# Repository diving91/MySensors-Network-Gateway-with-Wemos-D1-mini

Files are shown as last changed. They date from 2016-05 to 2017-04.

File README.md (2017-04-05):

# MySensors-Network-Gateway-with-Wemos-D1-mini
WiFi Gateway for MySensors network

Arduino sketch and PCB for an ESP8266 based WiFi Gateway for MySensors network (NRF24)</br>
It uses a Wemos D1 mini and a NRF24L01+ module boards</br>
It uses a mains power supply

It fits perfectly in a small and low cost enclosure from  SUPERTRONIC reference PP73N :</br>
http://www.tme.eu/fr/details/pp73n/boitiers-dappar-dalarme-et-de-capt/supertronic/

Note that in this PCB the Wemos module is mounted with</br>
-ESP WiFi module bottom side</br>
-CH340 & USB upper side</br>
This is the opposite side of common usage, but it greatly ease the use of the USB connector</br>
This is easily done since the Wemos D1 mini module comes with unsoldered breakout pins</br>
Take care when soldering the wemos D1 mini's breakout pins to solder them accordingly to the PCB layout of this repository</br>

<b>Mounting view</b></br>
     CH340 USB driver</br>
-----Wemos PCB-----</br>
        WiFi module</br>
---------- PCB ----------</br>

See also in Pictures folder</br>
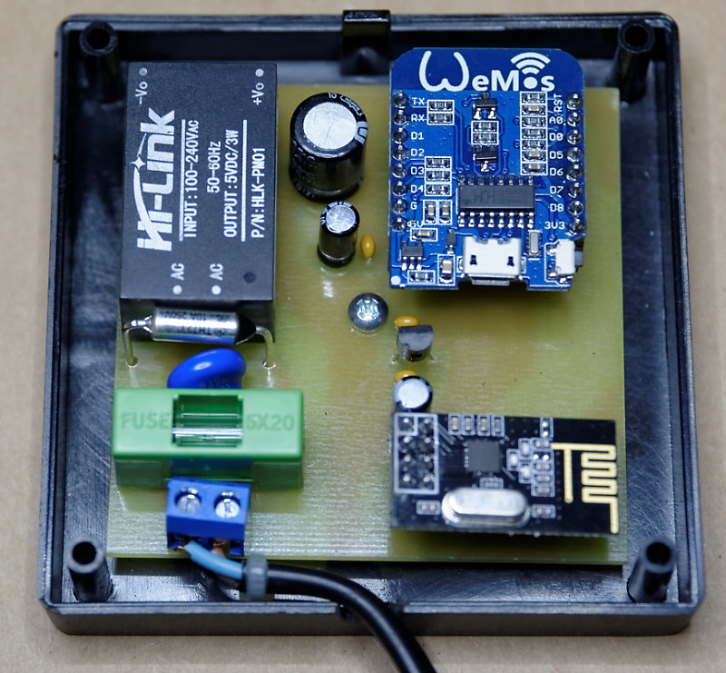
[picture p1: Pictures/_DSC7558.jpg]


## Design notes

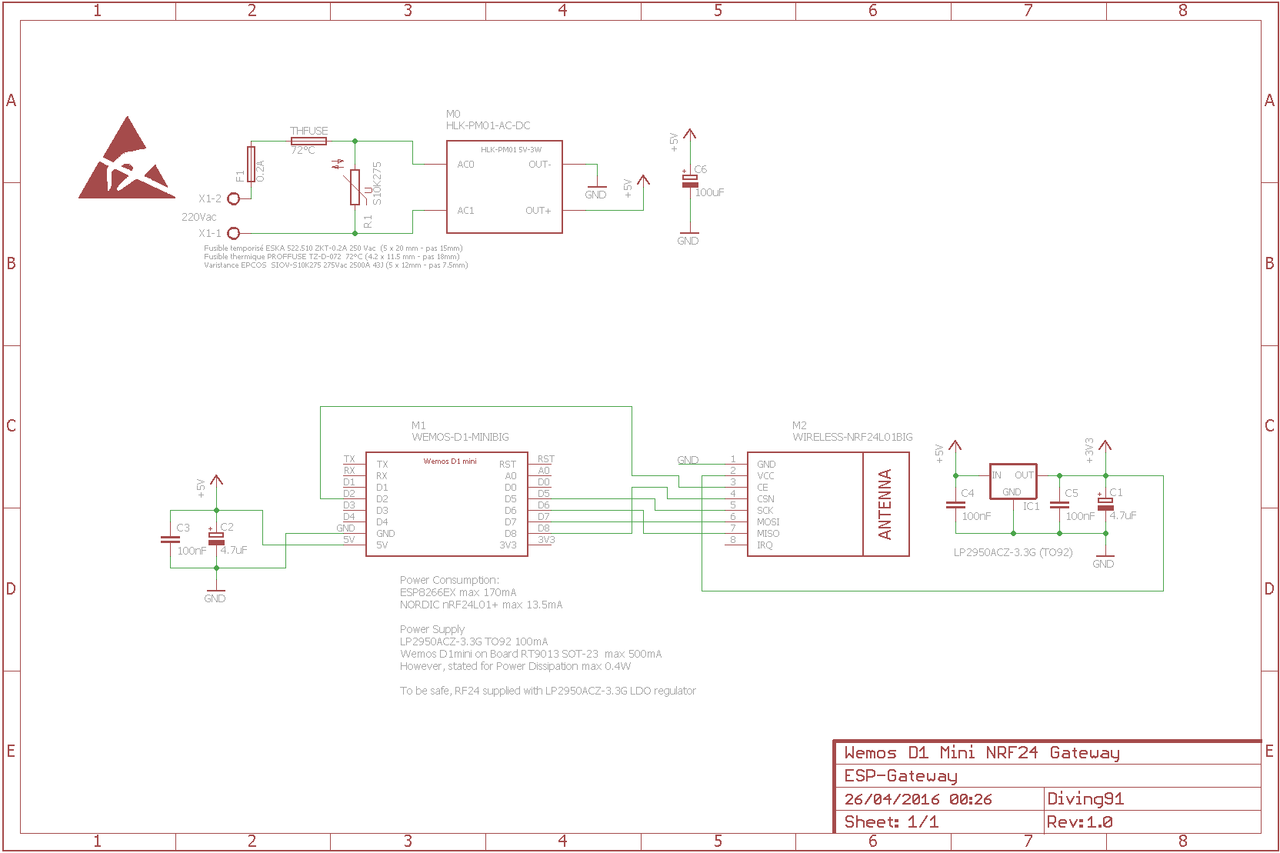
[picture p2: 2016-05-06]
Pictures/Node Schematics.png

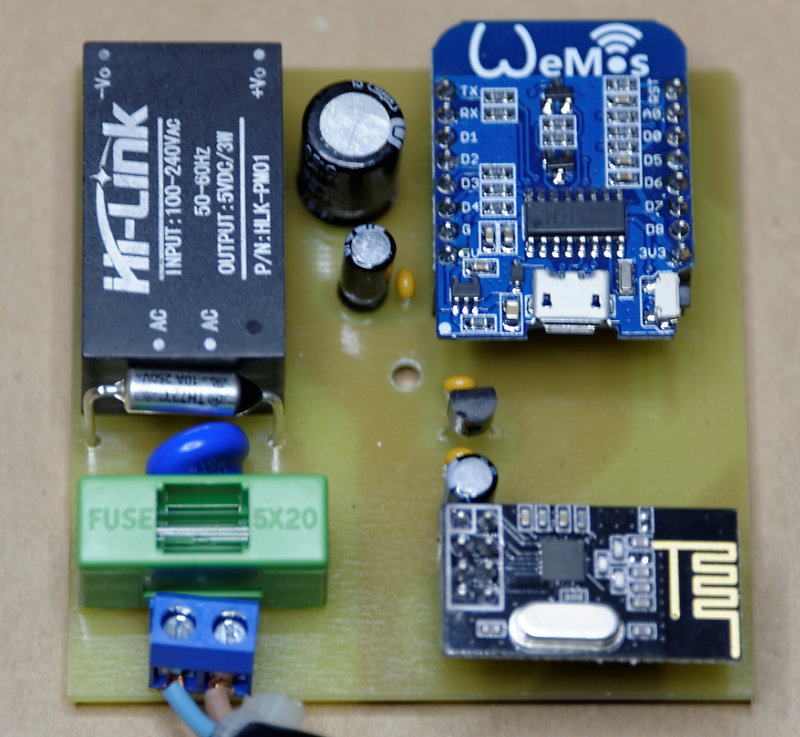
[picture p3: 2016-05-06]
Pictures/_DSC7557.jpg

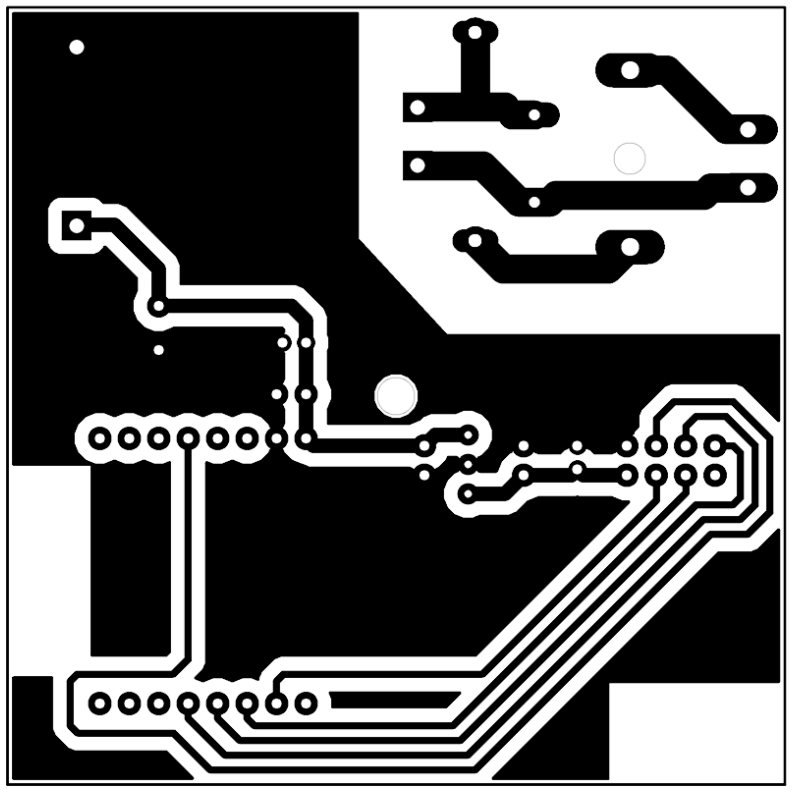
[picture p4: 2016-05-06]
Pictures/PCB view from copper side.png

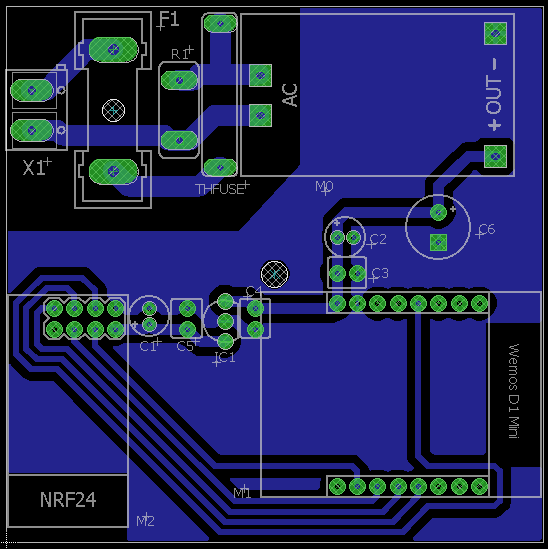
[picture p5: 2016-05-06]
Pictures/PCB Layout.png

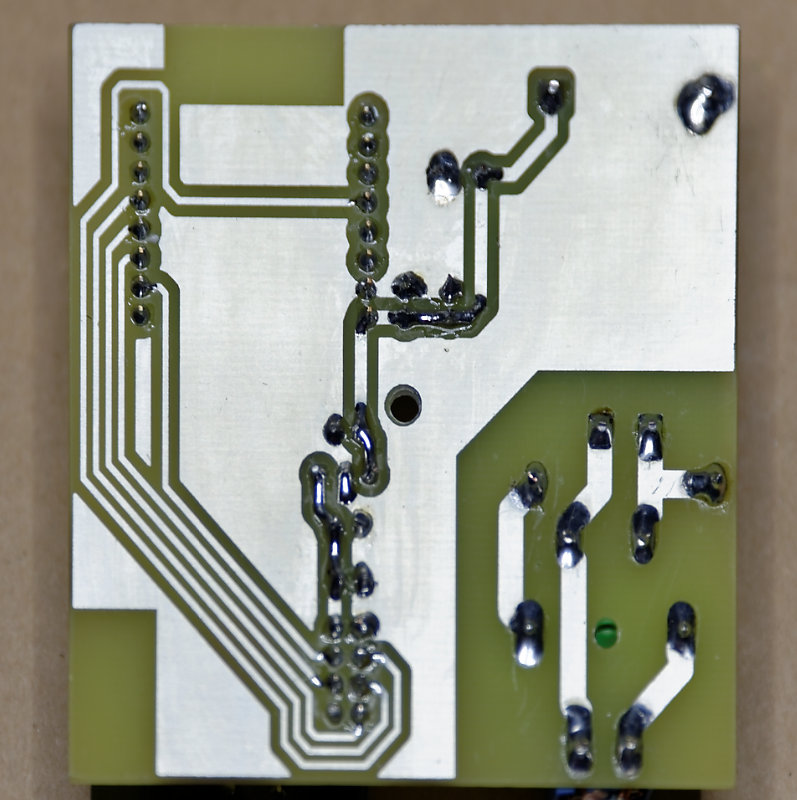
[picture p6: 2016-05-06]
Pictures/_DSC7555.jpg

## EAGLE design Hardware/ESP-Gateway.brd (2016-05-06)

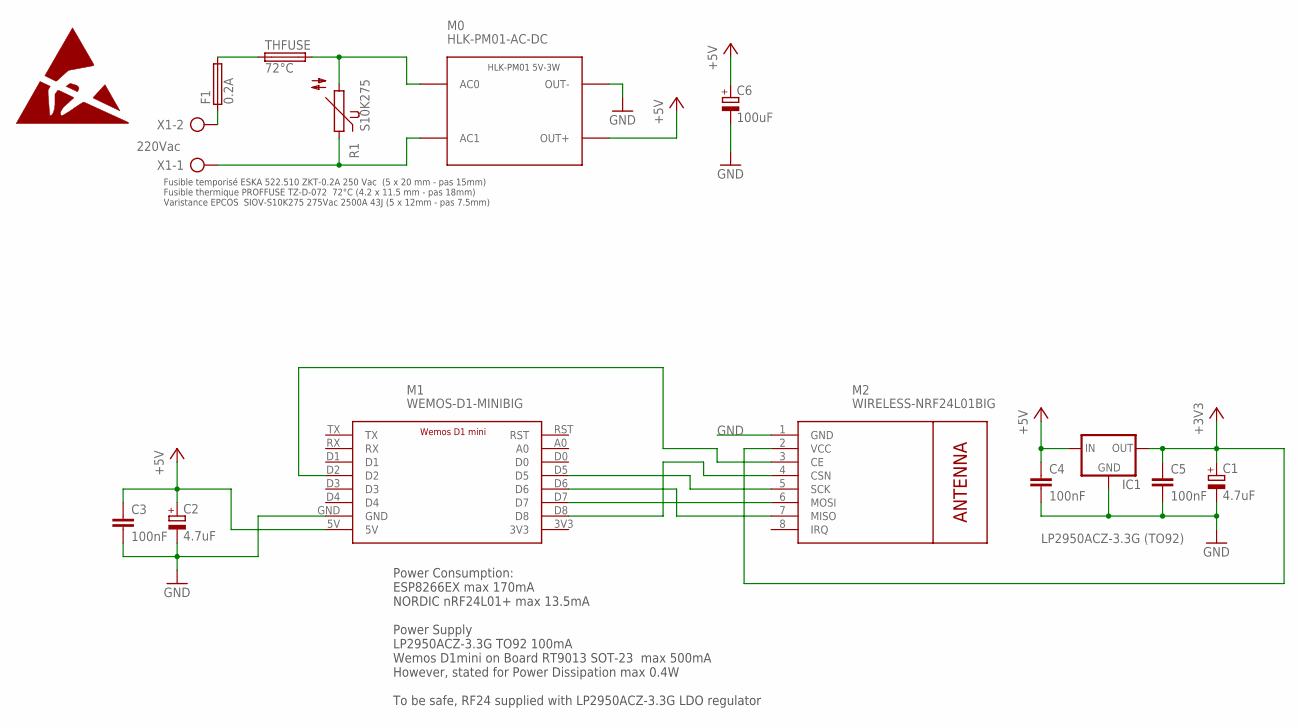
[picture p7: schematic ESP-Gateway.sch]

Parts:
C1, C2: 4.7uF; E2-5@1
C3, C4, C5: 100nF; C2.5-4
C6: 100uF; E3-8
F1: 0.2A; PTF75
IC1: LP2950ACZ-3.3G (TO92); DC-DC-TO92L
M0: HLK-PM01-AC-DC
M1: WEMOS-D1-MINIBIG; WEMOS-D1-MINI-DIY
M2: WIRELESS-NRF24L01BIG; WIRELESS-NRF24L01-DIY
R1: S10K275
THFUSE: 72°C; PROFFUSE-TZ-D
X1: 220Vac; DG301-5.0

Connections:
3V3: M1.3V3
+3V3: C1.+, C5.1, IC1.OUT, M2.2 (VCC)
+5V: C2.+, C3.1, C4.1, C6.+, IC1.IN, M0.OUT+, M1.5V
CE: M1.D2, M2.3 (CE)
CSN: M1.D8, M2.4 (CSN)
GND: C1.-, C2.-, C3.2, C4.2, C5.2, C6.-, IC1.GND, M0.OUT-, M1.GND, M2.1 (GND)
MISO: M1.D6, M2.7 (MISO)
MOSI: M1.D7, M2.6 (MOSI)
unnamed: M0.AC1, R1.1, X1.1
unnamed: F1.2, THFUSE.1
unnamed: F1.1, X1.2
unnamed: M0.AC0, R1.2, THFUSE.2
SCK: M1.D5, M2.5 (SCK)

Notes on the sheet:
Fusible temporisé ESKA 522.510 ZKT-0.2A 250 Vac (5 x 20 mm - pas 15mm) Fusible thermique PROFFUSE TZ-D-072 72°C (4.2 x 11.5 mm - pas 18mm) Varistance EPCOS SIOV-S10K275 275Vac 2500A 43J (5 x 12mm - pas 7.5mm)
Power Consumption: ESP8266EX max 170mA NORDIC nRF24L01+ max 13.5mA Power Supply LP2950ACZ-3.3G TO92 100mA Wemos D1mini on Board RT9013 SOT-23 max 500mA However, stated for Power Dissipation max 0.4W To be safe, RF24 supplied with LP2950ACZ-3.3G LDO regulator

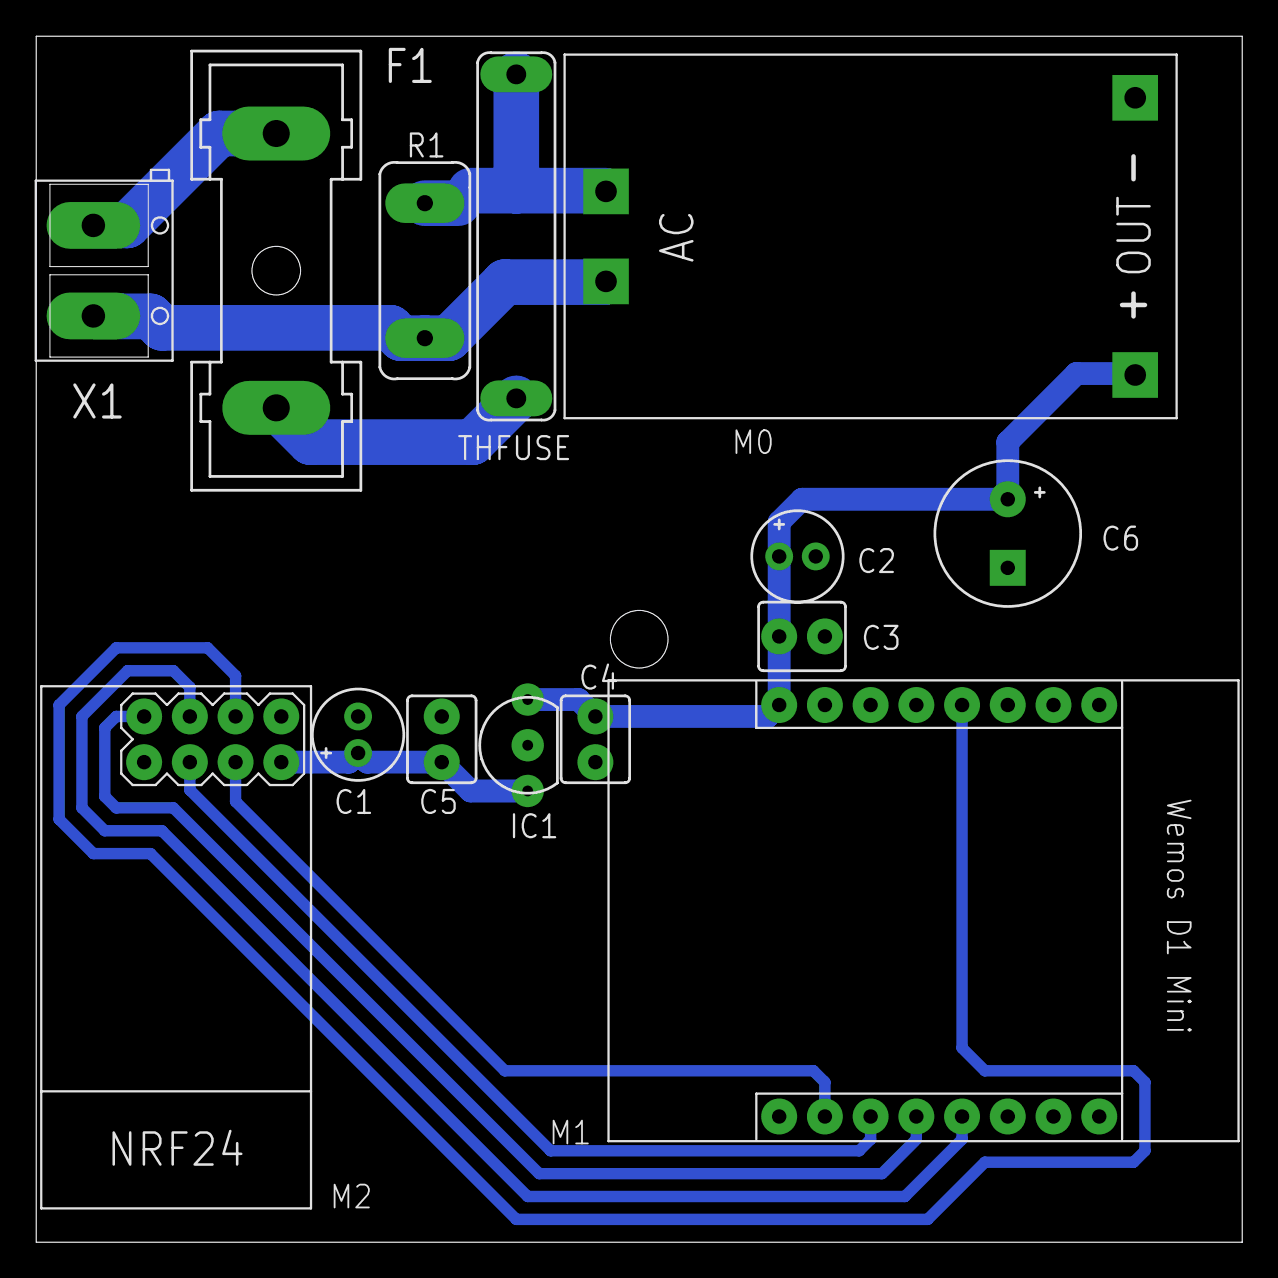
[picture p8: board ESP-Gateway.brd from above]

Board: 1 copper layer, 67.0 x 67.0 mm, 15 parts (0 on the bottom side), 12 nets.

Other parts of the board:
DRILEGEND: DRILEGEND

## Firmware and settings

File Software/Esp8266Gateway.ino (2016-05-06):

// Wemos D1 mini 160Mhz, Serial, 115200, 4M(3M SPIFFS), COMx
// Build with MySensors lib 1.5.4
// Build with ESP core lib 1.6.5-947-g39819f0

/**
 * The MySensors Arduino library handles the wireless radio link and protocol
 * between your home built sensors/actuators and HA controller of choice.
 * The sensors forms a self healing radio network with optional repeaters. Each
 * repeater and gateway builds a routing tables in EEPROM which keeps track of the
 * network topology allowing messages to be routed to nodes.
 *
 * Created by Henrik Ekblad <henrik.ekblad@mysensors.org>
 * Copyright (C) 2013-2015 Sensnology AB
 * Full contributor list: https://github.com/mysensors/Arduino/graphs/contributors
 *
 * Documentation: http://www.mysensors.org
 * Support Forum: http://forum.mysensors.org
 *
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
 *******************************
 *
 * REVISION HISTORY
 * Version 1.0 - Henrik EKblad
 * Contribution by a-lurker and Anticimex, 
 * Contribution by Norbert Truchsess <norbert.truchsess@t-online.de>
 * Contribution by Ivo Pullens (ESP8266 support)
 * 
 * DESCRIPTION
 * The EthernetGateway sends data received from sensors to the WiFi link. 
 * The gateway also accepts input on ethernet interface, which is then sent out to the radio network.
 *
 * VERA CONFIGURATION:
 * Enter "ip-number:port" in the ip-field of the Arduino GW device. This will temporarily override any serial configuration for the Vera plugin. 
 * E.g. If you want to use the defualt values in this sketch enter: 192.168.178.66:5003
 *
 * LED purposes:
 * - To use the feature, uncomment WITH_LEDS_BLINKING in MyConfig.h
 * - RX (green) - blink fast on radio message recieved. In inclusion mode will blink fast only on presentation recieved
 * - TX (yellow) - blink fast on radio message transmitted. In inclusion mode will blink slowly
 * - ERR (red) - fast blink on error during transmission error or recieve crc error  
 * 
 * See http://www.mysensors.org/build/ethernet_gateway for wiring instructions.
 * The ESP8266 however requires different wiring:
 * nRF24L01+  ESP8266
 * VCC        VCC
 * CE         GPIO4          
 * CSN/CS     GPIO15
 * SCK        GPIO14
 * MISO       GPIO12
 * MOSI       GPIO13
 *            
 * Not all ESP8266 modules have all pins available on their external interface.
 * This code has been tested on an ESP-12 module.
 * The ESP8266 requires a certain pin configuration to download code, and another one to run code:
 * - Connect REST (reset) via 10K pullup resistor to VCC, and via switch to GND ('reset switch')
 * - Connect GPIO15 via 10K pulldown resistor to GND
 * - Connect CH_PD via 10K resistor to VCC
 * - Connect GPIO2 via 10K resistor to VCC
 * - Connect GPIO0 via 10K resistor to VCC, and via switch to GND ('bootload switch')
 * 
  * Inclusion mode button:
 * - Connect GPIO5 via switch to GND ('inclusion switch')
 * 
 * Hardware SHA204 signing is currently not supported!
 *
 * Make sure to fill in your ssid and WiFi password below for ssid & pass.
 */
#define NO_PORTB_PINCHANGES 

#include <SPI.h>  

#include <MySigningNone.h> 
#include <MySigningAtsha204Soft.h>
#include <MyTransportNRF24.h>
#include <MyTransportRFM69.h>
#include <EEPROM.h>
#include <MyHwESP8266.h>
#include <ESP8266WiFi.h>

#include <MyParserSerial.h>  
#include <MySensor.h>  
#include <stdarg.h>
#include "GatewayUtil.h"

//Adapt to your network
const char *ssid =  "mySSID";    // cannot be longer than 32 characters!
const char *pass =  "myPWD"; //

#define INCLUSION_MODE_TIME 1 // Number of minutes inclusion mode is enabled
#define INCLUSION_MODE_PIN  5 // Digital pin used for inclusion mode button -> HSU D1 pin

#define RADIO_CE_PIN        4   // radio chip enable ->hsu number refer to gpio pin number ie D2 pin
#define RADIO_SPI_SS_PIN    15  // radio SPI serial select -> HSU D8 pin


#ifdef WITH_LEDS_BLINKING
#define RADIO_ERROR_LED_PIN BUILTIN_LED  // Error led pin
#define RADIO_RX_LED_PIN    BUILTIN_LED  // Receive led pin
#define RADIO_TX_LED_PIN    BUILTIN_LED  // the PCB, on board LED
#endif


// NRFRF24L01 radio driver (set low transmit power by default) 
MyTransportNRF24 transport(RADIO_CE_PIN, RADIO_SPI_SS_PIN, RF24_PA_LEVEL_GW);
//MyTransportRFM69 transport;


// Message signing driver (signer needed if MY_SIGNING_FEATURE is turned on in MyConfig.h)
#ifdef MY_SIGNING_FEATURE
MySigningNone signer;
//MySigningAtsha204Soft signer;
#endif

// Hardware profile 
MyHwESP8266 hw;

// Construct MySensors library (signer needed if MY_SIGNING_FEATURE is turned on in MyConfig.h)
// To use LEDs blinking, uncomment WITH_LEDS_BLINKING in MyConfig.h
MySensor gw(transport, hw
#ifdef MY_SIGNING_FEATURE
    , signer
#endif
#ifdef WITH_LEDS_BLINKING
  , RADIO_RX_LED_PIN, RADIO_TX_LED_PIN, RADIO_ERROR_LED_PIN
#endif
  );
  

#define IP_PORT 5003         // The port you want to open 
#define MAX_SRV_CLIENTS 3    // how many clients should be able to telnet to this ESP8266 - ie 2 JEEDOM + 1 Telnet

// a R/W server on the port
static WiFiServer server(IP_PORT);
static WiFiClient clients[MAX_SRV_CLIENTS];
static bool clientsConnected[MAX_SRV_CLIENTS];
static inputBuffer inputString[MAX_SRV_CLIENTS];

#define ARRAY_SIZE(x)  (sizeof(x)/sizeof(x[0]))

void output(const char *fmt, ... ) {
	char serialBuffer[MAX_SEND_LENGTH];
	va_list args;
	va_start (args, fmt );
	vsnprintf_P(serialBuffer, MAX_SEND_LENGTH, fmt, args);
	va_end (args);
	Serial.print(serialBuffer);
	for (uint8_t i = 0; i < ARRAY_SIZE(clients); i++) {
		if (clients[i] && clients[i].connected()) {
//			Serial.print("Client "); Serial.print(i); Serial.println(" write");
			clients[i].write((uint8_t*)serialBuffer, strlen(serialBuffer));
		}
	}
}

// HSU To display MAC Address
uint8_t MAC_array[6];
char MAC_char[18];

void setup() { 
	// Setup console
	hw_init();
	Serial.begin(115200);
	Serial.println(); Serial.println();
	Serial.println("ESP8266 MySensors Gateway");
	Serial.print("Connecting to "); Serial.println(ssid);

	(void)WiFi.begin(ssid, pass);
	// HSU Addition to disable AP and display MAC address
	WiFi.mode(WIFI_STA);
	WiFi.macAddress(MAC_array);
	Serial.print("MAC Address = ");
	for (int i = 0; i < sizeof(MAC_array); ++i){
		sprintf(MAC_char,"%s%02x:",MAC_char,MAC_array[i]);
	}
	Serial.println(MAC_char); //- See more at: http://www.esp8266.com/viewtopic.php?f=29&t=3587
	// End HSU
	
	while (WiFi.status() != WL_CONNECTED) {
		delay(500);
		Serial.print(".");
	}
	Serial.println("Connected!");
	Serial.print("IP: "); Serial.println(WiFi.localIP());
	Serial.println(); Serial.println(); //HSU
	Serial.flush();
  
	setupGateway(INCLUSION_MODE_PIN, INCLUSION_MODE_TIME, output);

	// Initialize gateway at maximum PA level, channel 70 and callback for write operations 
	gw.begin(incomingMessage, 0, true, 0);
  
	// start listening for clients
	server.begin();
	server.write("0;0;3;0;2;");server.write(LIBRARY_VERSION);  //HSU needed for Jeedom plugin
	server.setNoDelay(true);  
}

void loop() {
	gw.process();  
  
	checkButtonTriggeredInclusion();
	checkInclusionFinished();

	// Go over list of clients and stop any that are no longer connected.
	// If the server has a new client connection it will be assigned to a free slot.
	bool allSlotsOccupied = true;
	for (uint8_t i = 0; i < ARRAY_SIZE(clients); i++){
		if (!clients[i].connected()) {
			if (clientsConnected[i]) {
				Serial.print("Client "); Serial.print(i); Serial.println(" disconnected");
				clients[i].stop();
			}
			//check if there are any new clients
			if (server.hasClient()) {
				clients[i] = server.available();
				inputString[i].idx = 0;
				Serial.print("Client "); Serial.print(i); Serial.println(" connected"); 
				output(PSTR("0;0;%d;0;%d;Gateway startup complete.\n"),  C_INTERNAL, I_GATEWAY_READY);
			}
		}
		bool connected = clients[i].connected();
		clientsConnected[i] = connected;
		allSlotsOccupied &= connected;
	}
	if (allSlotsOccupied && server.hasClient()){
		//no free/disconnected spot so reject
		Serial.println("No free slot available");
		WiFiClient c = server.available();
		c.stop();
	}
  
	// Loop over clients connect and read available data
	for (uint8_t i = 0; i < ARRAY_SIZE(clients); i++){
		while(clients[i].connected() && clients[i].available()){
			char inChar = clients[i].read();
			if ( inputString[i].idx < MAX_RECEIVE_LENGTH - 1 ){ 
				// if newline then command is complete
				if (inChar == '\n'){  
					// a command was issued by the client
					// we will now try to send it to the actuator
					inputString[i].string[inputString[i].idx] = 0;
    
					// echo the string to the serial port
					Serial.print("Client "); Serial.print(i); Serial.print(": "); Serial.println(inputString[i].string);
    
					parseAndSend(gw, inputString[i].string);
    
					// clear the string:
					inputString[i].idx = 0;
					// Finished with this client's message. Next loop() we'll see if there's more to read.
					break;
				}
				else {  
					// add it to the inputString:
					inputString[i].string[inputString[i].idx++] = inChar;
				}
			}
			else {
				// Incoming message too long. Throw away 
				Serial.print("Client "); Serial.print(i); Serial.println(": Message too long");
				inputString[i].idx = 0;
				// Finished with this client's message. Next loop() we'll see if there's more to read.
				break;
			}
		}
	}
}

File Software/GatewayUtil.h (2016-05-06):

#ifndef __GATEWAYUTIL_H__
#define __GATEWAYUTIL_H__

#ifdef ARDUINO

static uint8_t inclusionTime = 1; // Number of minutes inclusion mode is enabled
static uint8_t pinInclusion =  5; // Input pin that should trigger inclusion mode

#define MAX_RECEIVE_LENGTH 100 // Max buffersize needed for messages coming from controller
#define MAX_SEND_LENGTH 120 // Max buffersize needed for messages destined for controller


typedef struct {
	char    string[MAX_RECEIVE_LENGTH];
	uint8_t idx;
} inputBuffer;

static volatile boolean buttonTriggeredInclusion;
static boolean inclusionMode; // Keeps track on inclusion mode
bool inclusionButtonSupported = false;
void (*serial)(const char *fmt, ... );

MyParserSerial parser;

void setInclusionMode(boolean newMode);

char convBuf[MAX_PAYLOAD*2+1];
unsigned long inclusionStartTime;


void startInclusionInterrupt() {
	buttonTriggeredInclusion = true;
}

void setupGateway(uint8_t _inc, uint8_t _incTime, void (* _serial)(const char *, ... )) {
	inclusionMode = 0;
	buttonTriggeredInclusion = false;
	serial = _serial;

	inclusionTime = _incTime;
	inclusionButtonSupported = (_inc != 255);
	if (inclusionButtonSupported){
		pinInclusion = _inc;

		// Setup digital in that triggers inclusion mode
		pinMode(pinInclusion, INPUT_PULLUP);

		// Add interrupt for inclusion button to pin
		attachInterrupt(pinInclusion, startInclusionInterrupt, FALLING);
	}
}

void incomingMessage(const MyMessage &message) {
	//  if (mGetCommand(message) == C_PRESENTATION && inclusionMode) {
	//	gw.rxBlink(3);
	//   } else {
	//	gw.rxBlink(1);
	//   }
	// Pass along the message from sensors to serial line
	serial(PSTR("%d;%d;%d;%d;%d;%s\n"),message.sender, message.sensor, mGetCommand(message), mGetAck(message), message.type, message.getString(convBuf));
} 



void checkButtonTriggeredInclusion() {
	if (inclusionButtonSupported){
		if (buttonTriggeredInclusion) {
			// Ok, someone pressed the inclusion button on the gateway
			// start inclusion mode for 1 munute.
			#ifdef DEBUG
				serial(PSTR("0;0;%d;0;%d;Inclusion started by button.\n"),  C_INTERNAL, I_LOG_MESSAGE);
			#endif
			buttonTriggeredInclusion = false;
			setInclusionMode(true);
		}
	}
}

void checkInclusionFinished() {
	if (inclusionMode && millis()-inclusionStartTime>60000UL*inclusionTime) {
		// inclusionTimeInMinutes minute(s) has passed.. stop inclusion mode
		setInclusionMode(false);
	}
}

void parseAndSend(MySensor &gw, char *commandBuffer) {
	boolean ok;
	MyMessage &msg = gw.getLastMessage();

	if (parser.parse(msg, commandBuffer)) {
		uint8_t command = mGetCommand(msg);

		if (msg.destination==GATEWAY_ADDRESS && command==C_INTERNAL) {
			// Handle messages directed to gateway
			if (msg.type == I_VERSION) {
				// Request for version
				serial(PSTR("0;0;%d;0;%d;%s\n"), C_INTERNAL, I_VERSION, LIBRARY_VERSION);
			}
			else if (msg.type == I_INCLUSION_MODE) {
				// Request to change inclusion mode
				setInclusionMode(atoi(msg.data) == 1);
			}
		}
		else {
			#ifdef WITH_LEDS_BLINKING
				gw.txBlink(1);
			#endif
			ok = gw.sendRoute(msg);
			if (!ok) {
				#ifdef WITH_LEDS_BLINKING
					gw.errBlink(1);
				#endif
			}
		}
	}
}

void setInclusionMode(boolean newMode) {
	if (newMode != inclusionMode) {
		inclusionMode = newMode;
		// Send back mode change on serial line to ack command
		serial(PSTR("0;0;%d;0;%d;%d\n"), C_INTERNAL, I_INCLUSION_MODE, inclusionMode?1:0);

		if (inclusionMode) {
			inclusionStartTime = millis();
		}
	}
}


#else
#error This example is only for use on Arduino.
#endif // ARDUINO

#endif 

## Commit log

2016-05-06 Node Schematics
2016-05-06 PCB Layout
2016-05-06 Add PCB Layout
2016-05-06 Add PCB view from copper side
2016-05-06 Add Eagle 7.5.0 sch file
    [ESP-Gateway.sch]
2016-05-06 Add Eagle 7.5.0 brd file
    [ESP-Gateway.brd]
2016-05-06 Mounting photos

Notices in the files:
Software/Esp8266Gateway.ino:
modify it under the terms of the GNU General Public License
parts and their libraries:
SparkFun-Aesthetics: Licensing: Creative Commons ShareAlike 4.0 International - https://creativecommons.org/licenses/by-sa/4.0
